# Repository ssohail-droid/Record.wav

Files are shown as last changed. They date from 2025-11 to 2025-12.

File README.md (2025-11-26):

# Record.wav
A standalone ESP32 audio player that streams CD-quality WAV files from an SD card to Bluetooth headphones or speakers. Includes smooth A2DP transmission, a ring-buffered audio pipeline, a 128×128 OLED UI, volume control, next/pause functions, and a simple physical control interface.

<p align="center">
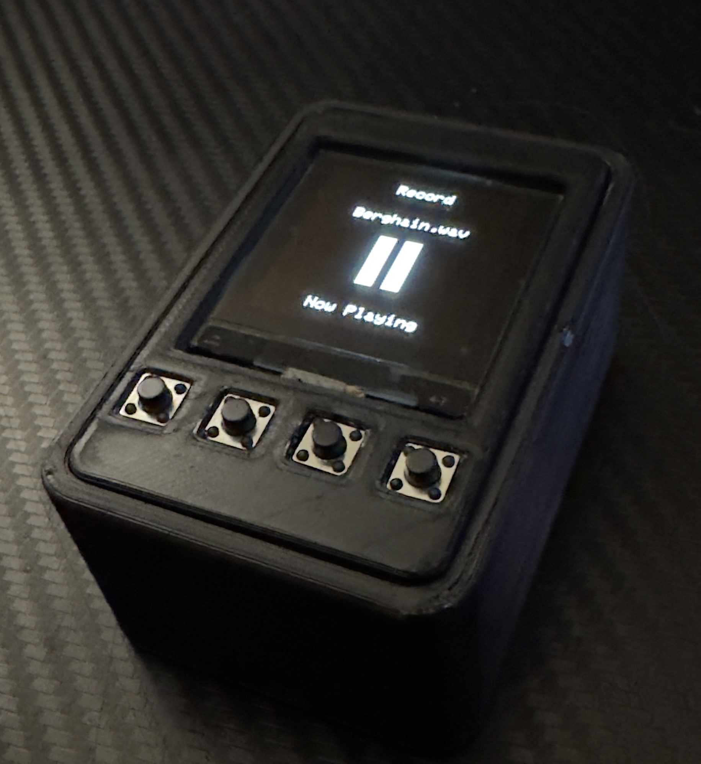
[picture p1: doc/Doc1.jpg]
  
</p>

## Required Components & Tools:
- ESP32-WROOM-32 Development Board
(Recommended: 8 MB Flash version — stable for Bluetooth A2DP)
- SD Card Module (SPI-based)
Compatible with 3.3V logic
Example: HW-125, Catalex, or any generic SPI SD reader
- MicroSD Card (FAT32 formatted)
- SH1107 or SSD1306 128×128 OLED Display (I²C)
4-pin version (GND, VCC, SDA, SCL)
- WAV-compatible Bluetooth headphones or speakers
ESP32 streams via A2DP sink mode

## Step 1: Print the Case

### [Download the print here](https://github.com/ssohail-droid/Record.wav/tree/main/STL)

<p align="center">
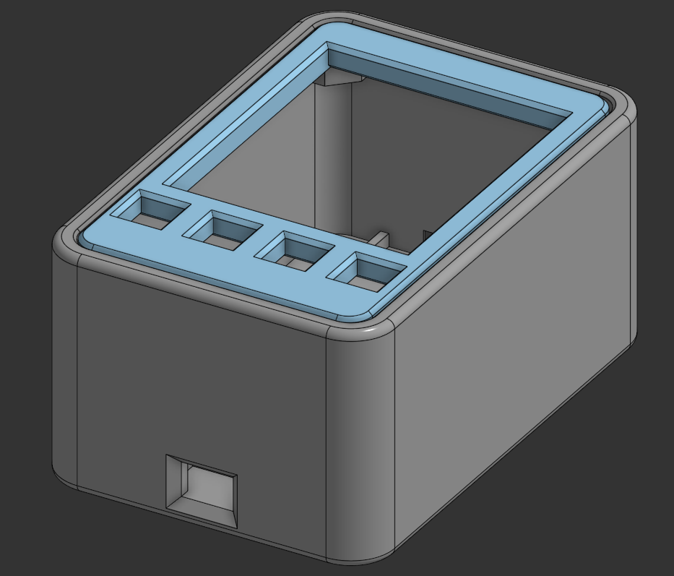
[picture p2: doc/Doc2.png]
  
</p>

## Step 2: Wiring

### Complete Wiring Overview (Side-by-Side)

| OLED Wiring (ESP32 → OLED) | SD Module Wiring (ESP32 → SD) | Button Wiring (Function → Pin → GND) |
| --- | --- | --- |
| 3.3V → VCC | GPIO5  → CS | Play/Pause → GPIO25 → GND |
| GND  → GND | GPIO18 → SCK | Next Track → GPIO14 → GND |
| GPIO21 → SDA | GPIO23 → MOSI | Volume − → GPIO27 → GND |
| GPIO22 → SCL | GPIO19 → MISO | Volume + → GPIO26 → GND |
| | 3.3V → VCC | |
| | GND → GND | |

## Step 3: Programming

### [Get the code here](https://github.com/ssohail-droid/Record.wav/blob/main/Code/BT-Code)

- Upload the code from the Arduino IDE and flash it to the board.

## Step 4: Get the music

- Disclaimer: This WAV player project does not support or encourage piracy. All audio used should be legally obtained.
- This WAV player only supports `.wav` files. I personally like using this website:
### [Here](https://www.freeconvert.com/mp3-to-wav)
-Then upload the music onto the SD card.

## Congratulations! You now have Record.wav!!!!!!.

<p align="center">
  <a href="https://example.com">
    Demo GIF
  </a>
</p>

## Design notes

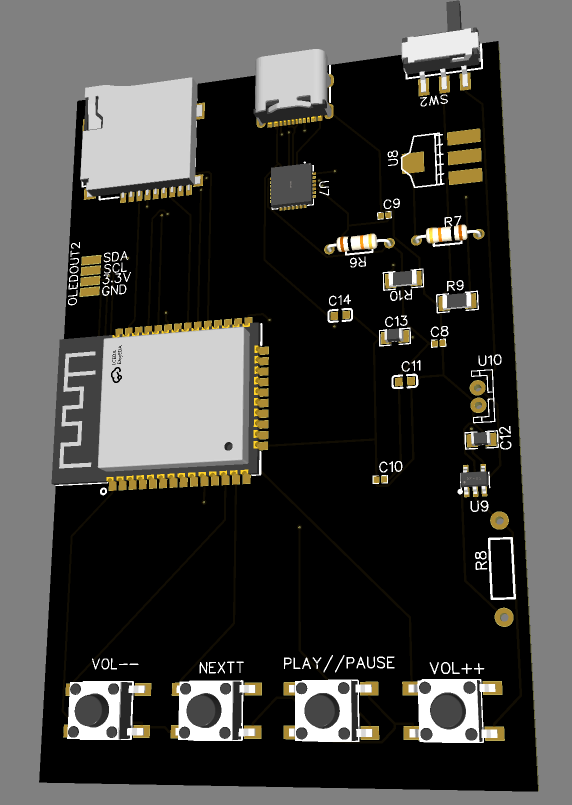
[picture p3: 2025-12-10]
Record PCB V2/brave_screenshot_easyeda.com.png

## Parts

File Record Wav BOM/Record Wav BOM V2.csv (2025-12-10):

Product name | Product amoun | Product unit price | Product running total. | Product description | Product link
SILICON LABS CP2102N-A02-GQFN28R | 1 | $1.58 | $1.58 | Transceiver QFN-28-EP(5x5) Interface Controllers RoHS | https://www.lcsc.com/product-detail/C964632.html?s_z=n_CP2102N-A02-GQFN28R
SHOU HAN TF PUSH | 10 | $0.0556 | $0.56 | -25℃~+90℃ Push-Push 2mm Connector and Ejector MicroSD Card (TF Card) SMD PC Card Sockets RoHS | https://www.lcsc.com/product-detail/C393941.html
XUNPU TS-1002S-07026C | 10 | $0.0479 | $0.48 | Without Bracket 6mm 12V 6mm Round Button SPST 50mA SMD-4P,6x6mm Tactile Switches RoHS | https://www.lcsc.com/product-detail/C455114.html
FOJAN FRC1206F5101TS | 100 | $0.0026 | $0.26 | 250mW 5.1kΩ 200V ±100ppm/℃ Thick Film Resistor ±1% 1206 Chip Resistor - Surface Mount RoHS | https://www.lcsc.com/product-detail/C2933721.html
YAGEO RC0603FR-0710KL | 100 | $0.0011 | $0.11 | 100mW 10kΩ 75V ±100ppm/℃ Thick Film Resistor ±1% 0603 Chip Resistor - Surface Mount RoHS | https://www.lcsc.com/product-detail/C98220.html?s_z=n_C98220
SHOU HAN MST-12D18G4 SPDT Slide Switch | 5 | $0.0727 | $0.36 | 100mA Surface Mount, Right Angle SPDT 12V Black 10,000 Cycles SMD Slide Switches RoHS | https://www.lcsc.com/product-detail/C49023767.html?s_z=n_C49023767
ESPRESSIF ESP32-WROOM-32-N4 | 1 | $4.1798 | $4.18 | ESP32-DOWDQ6 -97dBm SMD,25.5x18mm RF Transceiver Modules and Modems RoHS | https://www.lcsc.com/product-detail/C82899.html
Advanced Monolithic Systems AMS1117-3.3 | 5 | $0.1651 | $0.83 | 72dB@(120Hz) Positive Fixed 3.3V SOT-223 Voltage Regulators - Linear, Low Drop Out (LDO) Regulators RoHS | https://www.lcsc.com/product-detail/C6186.html
MICROCHIP MCP73831T-2ACI/OT | 5 | $0.8821 | $4.41 | Miniature Single-Cell, Fully Integrated Li-Ion, Li-Polymer Charge Management Controllers | https://www.lcsc.com/product-detail/C424093.html
SHOU HAN TYPE-C 16PIN 2MD(073) | 10 | $0.0594 | $0.59 | 1 16P -25℃~+85℃ Type-C SMD USB, DVI, HDMI Connector Assemblies RoHS | https://www.lcsc.com/product-detail/C2765186.html
490-GRM21BR71A475KE51LCT-ND | 10 | $0.06400 | $0.64 | CAP CER 4.7UF 10V X7R 0805 | https://www.digikey.com/en/products/detail/murata-electronics/GRM21BR71A475KE51L/7362918
478-KGM21AR71E105JUCT-ND | 10 | $0.19400 | $1.94 | CAP CER 1UF 25V X7R 0805 | https://www.digikey.com/en/products/detail/kyocera-avx/08053C105JAT2A/1602174
1276-1869-1-ND | 10 | $0.04500 | $0.45 | CAP CER 10UF 25V X5R 0603 | https://www.digikey.com/en/products/detail/samsung-electro-mechanics/CL10A106MA8NRNC/3887527
3.7V 2000mAh Pouch Li-Po | 1 | $2.50 | $2.50 | KC Approved Rechargeable 3.7V 2000mAh Pouch Li-Po & Li-Ion Lithium Batteries 654060 | https://www.alibaba.com/product-detail/KC-Approved-Rechargeable-3-7V-2000mAh_1601519399317.html
1.5" SH1107 128x128 OLED Display | 1 | $5.00 | $5.00 | HiLetgo 1.5" SH1107 128x128 OLED Display Module 1.5 Inch IIC I2C 4 Pin OLED Screen LCD Display White | https://www.google.com/aclk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
PCB | 5 | $0.80 | $4.00 | The Main PCB | https://cart.jlcpcb.com/quote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
Stencil | 1 | $7.00 | $7.00 | For reflowing | https://cart.jlcpcb.com/quote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

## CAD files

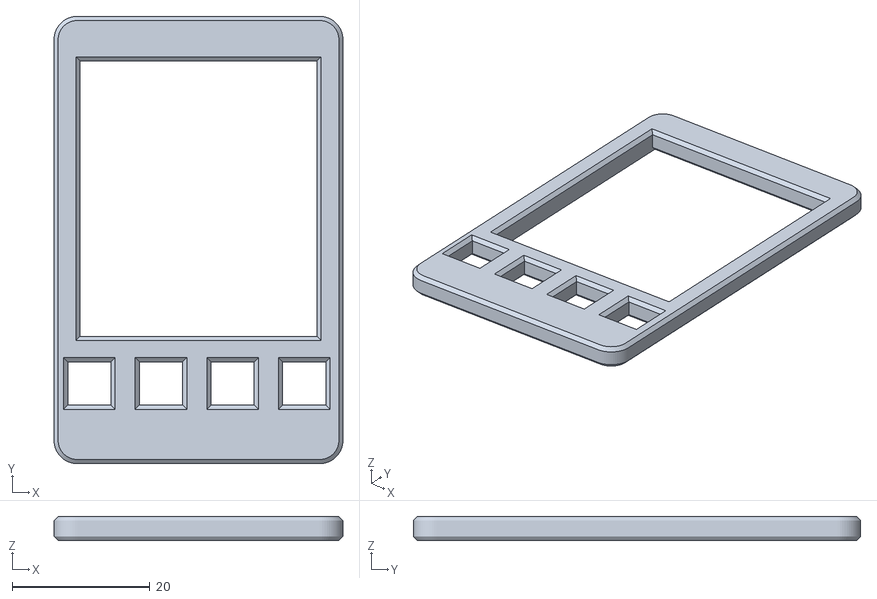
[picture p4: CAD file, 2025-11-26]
STL/v2.1 - Part 1.stl
42.0 x 65.0 x 3.50

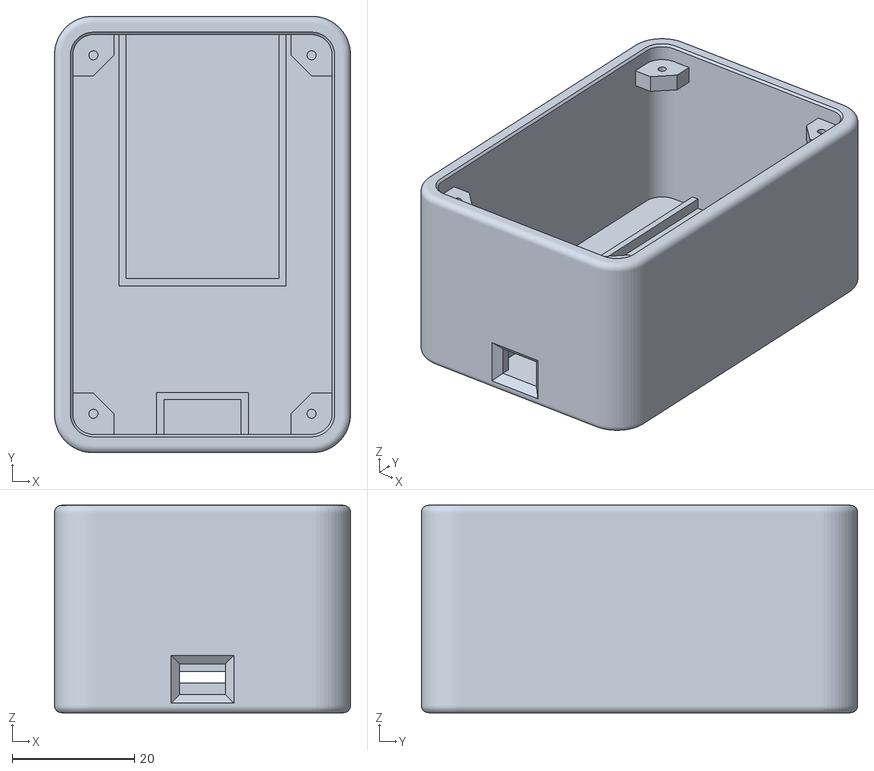
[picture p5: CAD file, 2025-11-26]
STL/v2.1 - Part 2.stl
48.5 x 71.5 x 34.0

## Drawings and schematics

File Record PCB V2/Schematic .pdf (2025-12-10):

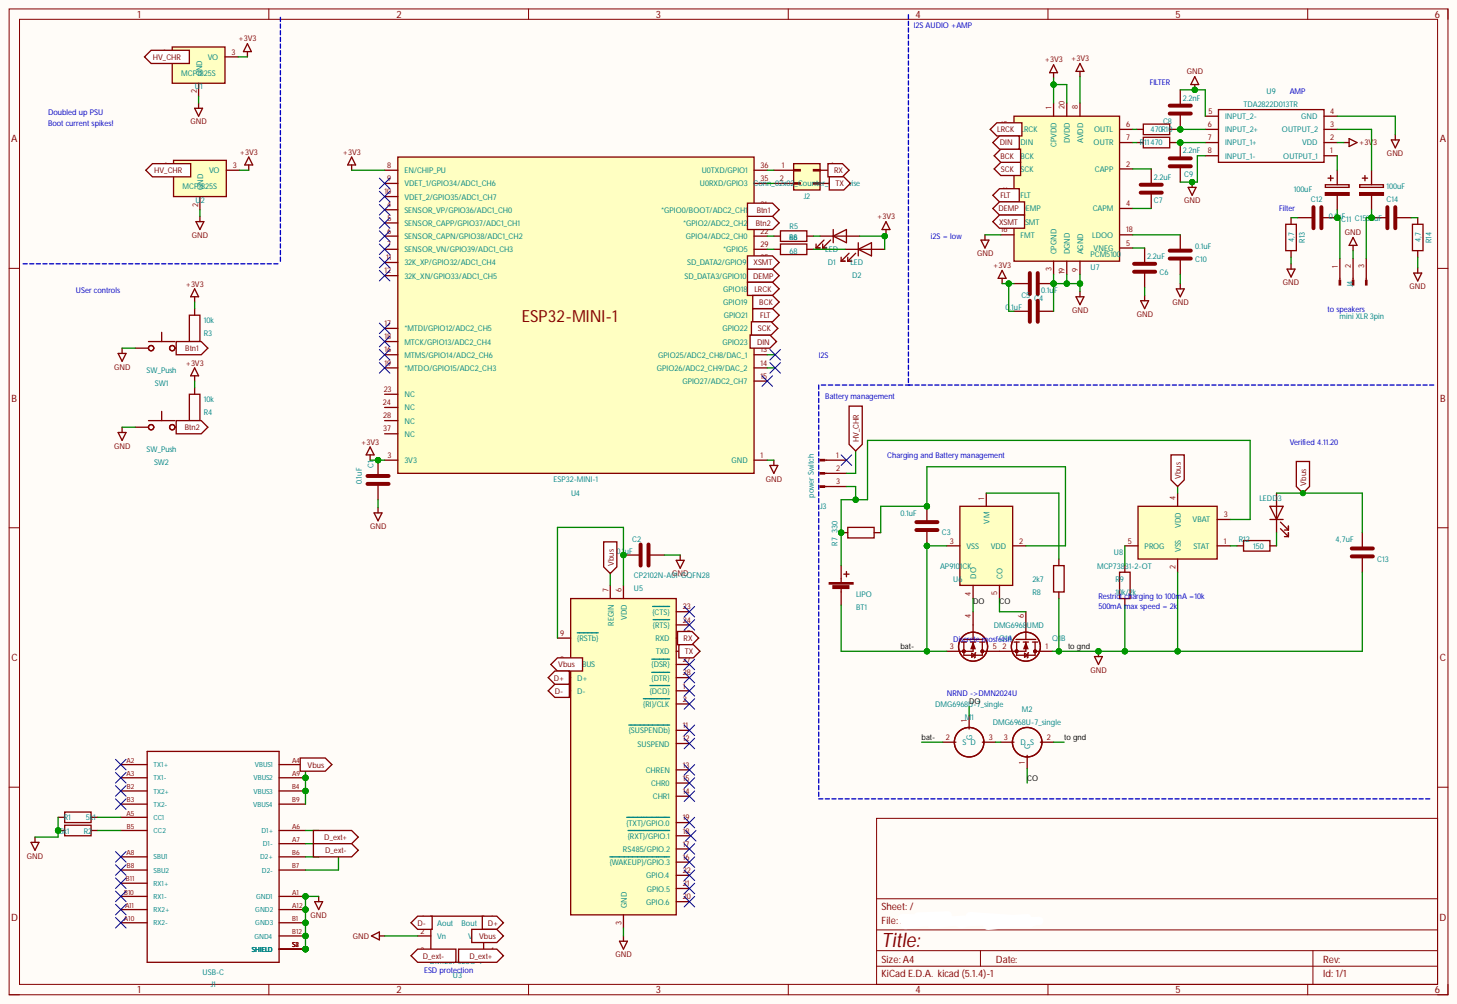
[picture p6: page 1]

I2S AUDIO +AMP

Charging and Battery management

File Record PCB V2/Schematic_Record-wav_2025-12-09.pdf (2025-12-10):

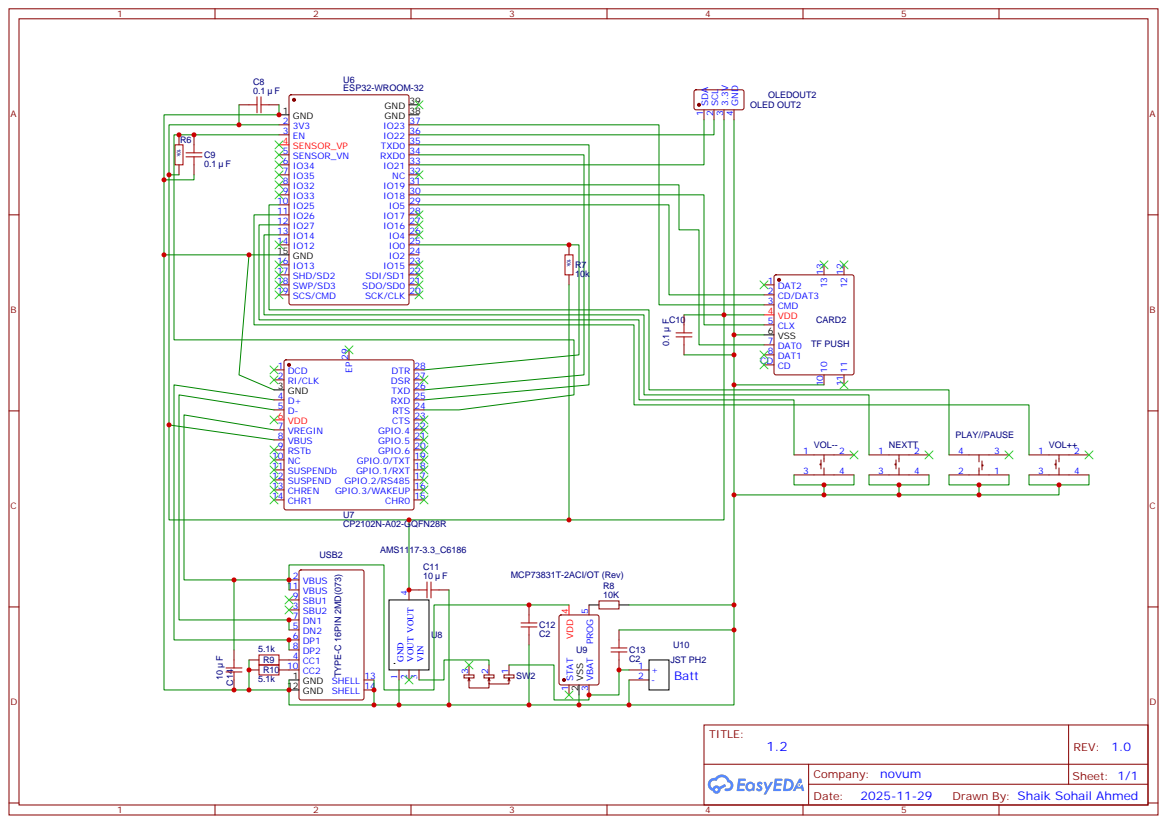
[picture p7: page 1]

Drawn By: Shaik Sohail Ahmed

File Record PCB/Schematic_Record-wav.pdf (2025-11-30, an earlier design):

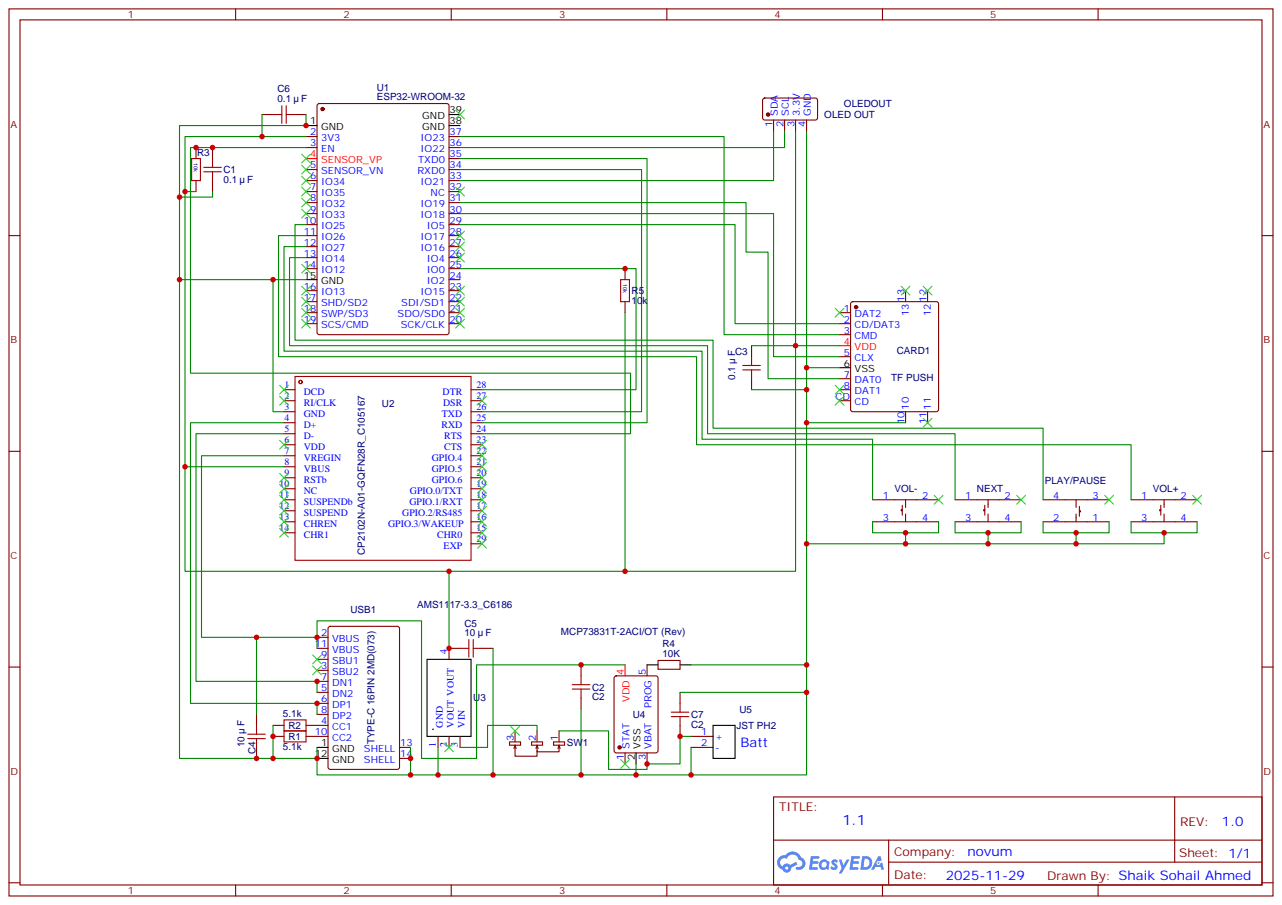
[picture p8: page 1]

Drawn By: Shaik Sohail Ahmed

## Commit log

2025-11-26 Enhance README with wiring diagrams
    Added detailed wiring instructions for ESP32 DEVKIT V1, OLED, and SD Card Module.
2025-11-26 Update README with wiring instructions
    Added wiring details for OLED and SD module connections.
2025-11-26 Add ESP32 Bluetooth WAV Player functionality
    Initial implementation of an ESP32 Bluetooth WAV player with volume control and song management.
2025-11-26 Revise wiring section in README.md
    Updated wiring instructions for ESP32, OLED, and SD module with a side-by-side comparison format.
2025-11-26 Update README with new wiring section
2025-12-10 Add new file V2 for Record PCB
2025-12-10 Add initial content to Record Wav BOM/Test
